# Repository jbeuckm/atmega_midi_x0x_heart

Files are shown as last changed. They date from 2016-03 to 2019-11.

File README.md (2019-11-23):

# MIDI interface for x0x heart

Atmega328 MIDI interface for the x0x heart http://www.openmusiclabs.com/projects/x0x-heart/

One-sided for easy home DIY.

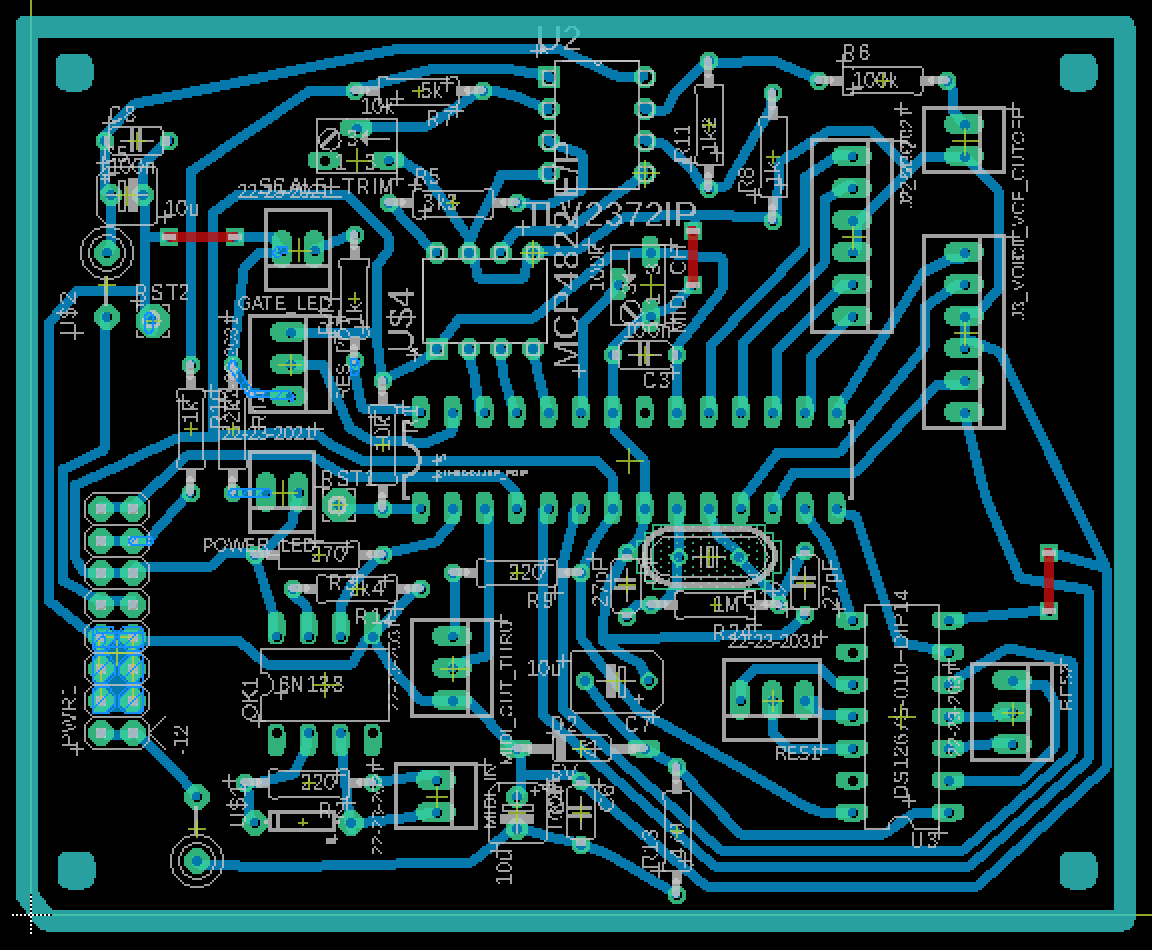
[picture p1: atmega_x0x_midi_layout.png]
atmega_x0x_midi_layout


### NOTE ON/OFF

The gate pins of the eurorack connector are raised to 5V during the note. The "CV" pins of the eurorack connector are set to 1V/oct pitch control voltage. A pitch scale trimpot can be used to tune the x0x.

### Continuous Controllers

| MIDI CC | Function |
| --- | --- |
| 1 | Envelope |
| 2 | Resonance |
| 11 | Accent |
| 65 | Slide above 64 / No slide below 64 |
| 70 | Saw level |
| 71 | Square level |
| 72 | Decay |
| 74 | VCF Cutoff |

### System Exclusive

MIDI Sysex messages for this device begin with a four-byte prefix of the Sysex status byte, manufacturer ID, model ID and device ID.

`F0` sysex start

`77 33` manufacturer ID, model ID

`xx` device ID as set by trim pot

--

#### Set MIDI Channel

At startup, the MIDI channel of the device is the same as the device ID set with the trim pot.

A seven-byte sysex message can be used to change the channel of the interface.

`F0 77 33 xx` sysex prefix

`00` select MIDI channel parameter

`xx` new MIDI channel (0 for omni)

`F7` end of message

--

#### Patch Dump Request

A six-byte sysex message can be used to request a dump of the current voice parameters.

`F0 77 33 xx` sysex prefix

`01` patch dump request

`F7` end of message

The interface will then send a patch dump sysex message that encodes the current voice parameter values.

`F0 77 33 xx` sysex prefix

`02` patch dump

`ee rr aa pp ss qq dd ff`

envelope, resonance, accent, slide, saw, square, decay, cutoff (eight bytes)

`F7` end of message

This dumped patch data can be used to set all voice parameters by sending it back to the interface.

--

#### Save Patch

`F0 77 33 xx` sysex prefix

`11` save patch

`pp` patch number (0-127)

`F7` end of message

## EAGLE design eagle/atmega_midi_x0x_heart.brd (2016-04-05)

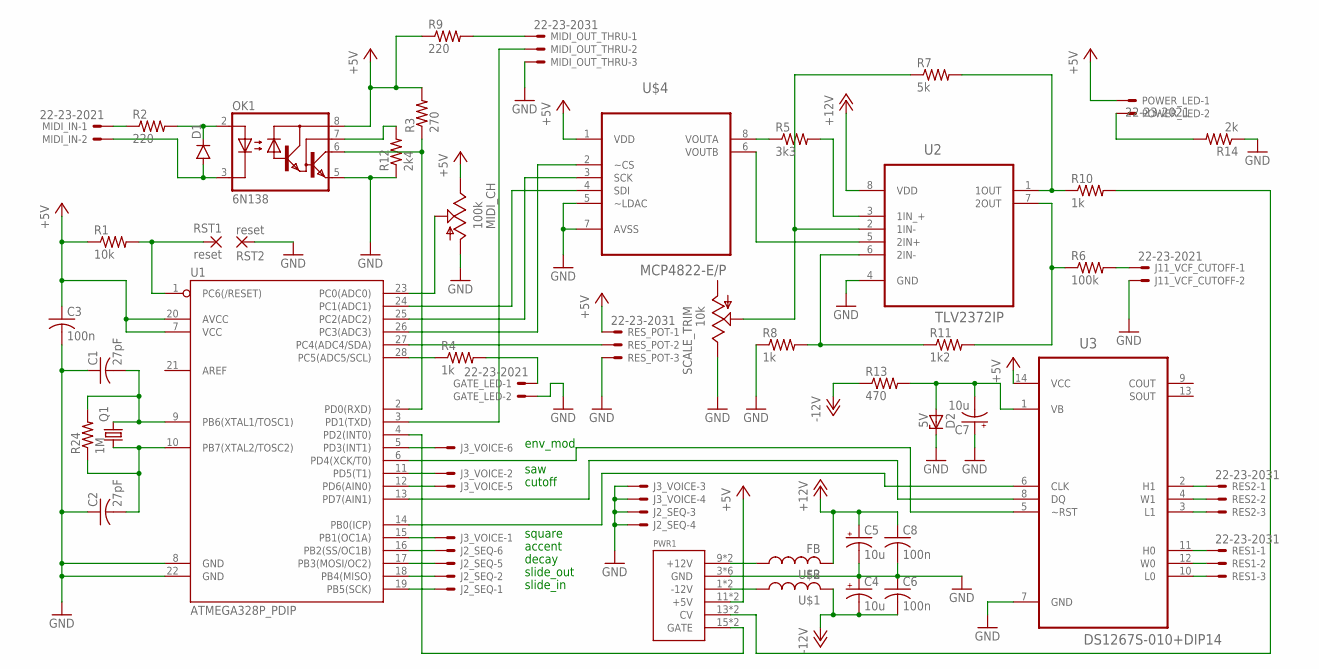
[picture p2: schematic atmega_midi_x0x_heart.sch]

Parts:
C1, C2: 27pF; C050-024X044
C3, C6, C8: 100n; C050-024X044
C4, C5: 10u; B45181A
C7: 10u; B45181B
D1: DIODE1N4148; DIODE-1N4148
D2: 5V; DO35Z10
GATE_LED: 22-23-2021
J2_SEQ, J3_VOICE: 22-23-2061
J11_VCF_CUTOFF: 22-23-2021
MIDI_CH: 100k; B64W
MIDI_IN: 22-23-2021
MIDI_OUT_THRU: 22-23-2031
OK1: 6N138; DIL08
POWER_LED: 22-23-2021
PWR1: POWER; POWER_16
Q1: CRYSTALHC49S; HC49/S
R1: 10k; 0207/10
R2, R9: 220; 0207/10
R3: 270; 0207/10
R4, R8, R10: 1k; 0207/10
R5: 3k3; 0207/10
R6: 100k; 0207/10
R7: 5k; 0207/10
R11: 1k2; 0207/10
R12: 2k4; 0207/10
R13: 470; 0207/10
R14: 2k; 0207/10
R24: 1M; 0207/10
RES1, RES2: 22-23-2031
RES_POT: 22-23-2031
RST1, RST2: reset; 2,54/0,9
SCALE_TRIM: 10k; B64W
U1: ATMEGA328P_PDIP; DIL28-3
U2: TLV2372IP; DIP254P762X508-8
U3: DS1267S-010+DIP14; DIP14
U$1, U$2: FB
U$4: MCP4822-E/P; DIP254P762X432-8

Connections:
+5V: C3.1, MIDI_CH.E, OK1.8 (VCC), POWER_LED.1, PWR1.11 (+5V), PWR1.12 (+5V), R1.1, R3.2, R9.1, RES_POT.1, U1.7 (VCC), U1.20 (AVCC), U3.14 (VCC), U$4.1 (VDD)
+12V: C5.+, C8.1, U2.8 (VDD), U$2.P$2 (2)
-12V: C4.-, C6.2, R13.1, U$1.P$2 (2)
GND: C1.1, C2.1, C3.2, C4.+, C5.-, C6.1, C7.+, C8.2, D2.C, GATE_LED.2, J2_SEQ.3, J2_SEQ.4, J3_VOICE.3, J3_VOICE.4, J11_VCF_CUTOFF.2, MIDI_CH.A, MIDI_OUT_THRU.3, OK1.5 (GND), PWR1.3 (GND), PWR1.4 (GND), PWR1.5 (GND), PWR1.6 (GND), PWR1.7 (GND), PWR1.8 (GND), R8.1, R12.1, R14.1, RES_POT.3, RST2.1, SCALE_TRIM.E, U1.8 (GND), U1.22 (GND), U2.4 (GND), U3.7 (GND), U$4.5 (~LDAC), U$4.7 (AVSS)
unnamed: J3_VOICE.6, U1.5 (PD3(INT1))
unnamed: R5.1, U$4.8 (VOUTA)
unnamed: D1.A, MIDI_IN.2, OK1.3 (C)
unnamed: C1.2, Q1.2, R24.2, U1.9 (PB6(XTAL1/TOSC1))
unnamed: C2.2, Q1.1, R24.1, U1.10 (PB7(XTAL2/TOSC2))
unnamed: R5.2, U2.3 (1IN_+)
unnamed: D1.C, OK1.2 (A), R2.2
unnamed: MIDI_IN.1, R2.1
unnamed: J3_VOICE.1, U1.15 (PB1(OC1A))
unnamed: J3_VOICE.2, U1.11 (PD5(T1))
unnamed: PWR1.9 (+12V), PWR1.10 (+12V), U$2.P$1 (1)
unnamed: R7.1, SCALE_TRIM.S, U2.2 (1IN-)
unnamed: R8.2, R11.1, U2.6 (2IN-)
unnamed: U2.5 (2IN+), U$4.6 (VOUTB)
unnamed: PWR1.13 (CV), PWR1.14 (CV), R10.2
unnamed: J3_VOICE.5, U1.12 (PD6(AIN0))
unnamed: R6.1, R11.2, U2.7 (2OUT)
unnamed: J2_SEQ.1, U1.19 (PB5(SCK))
unnamed: MIDI_CH.S, U1.23 (PC0(ADC0))
unnamed: J2_SEQ.2, U1.18 (PB4(MISO))
unnamed: J2_SEQ.5, U1.17 (PB3(MOSI/OC2))
unnamed: U1.6 (PD4(XCK/T0)), U3.5 (~RST)
unnamed: J2_SEQ.6, U1.16 (PB2(SS/OC1B))
unnamed: GATE_LED.1, R4.2
unnamed: U1.25 (PC2(ADC2)), U$4.3 (SCK)
unnamed: U1.24 (PC1(ADC1)), U$4.4 (SDI)
unnamed: R7.2, R10.1, U2.1 (1OUT)
unnamed: R4.1, U1.28 (PC5(ADC5/SCL))
unnamed: J11_VCF_CUTOFF.1, R6.2
unnamed: OK1.6 (VO), R3.1, U1.2 (PD0(RXD))
unnamed: RES2.2, U3.4 (W1)
unnamed: RES2.1, U3.2 (H1)
unnamed: RES2.3, U3.3 (L1)
unnamed: RES1.2, U3.12 (W0)
unnamed: RES1.1, U3.11 (H0)
unnamed: RES1.3, U3.10 (L0)
unnamed: U1.14 (PB0(ICP)), U3.6 (CLK)
unnamed: RES_POT.2, U1.27 (PC4(ADC4/SDA))
unnamed: MIDI_OUT_THRU.1, R9.2
unnamed: PWR1.15 (GATE), PWR1.16 (GATE), U1.4 (PD2(INT0))
unnamed: U1.13 (PD7(AIN1)), U3.8 (DQ)
unnamed: MIDI_OUT_THRU.2, U1.3 (PD1(TXD))
unnamed: R1.2, RST1.1, U1.1 (PC6(/RESET))
unnamed: OK1.7 (VB), R12.2
unnamed: U1.26 (PC3(ADC3)), U$4.2 (~CS)
unnamed: POWER_LED.2, R14.2
unnamed: PWR1.1 (-12V), PWR1.2 (-12V), U$1.P$1 (1)
unnamed: C7.-, D2.A, R13.2, U3.1 (VB)

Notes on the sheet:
square
saw
cutoff
env_mod
slide_in
slide_out
decay
accent

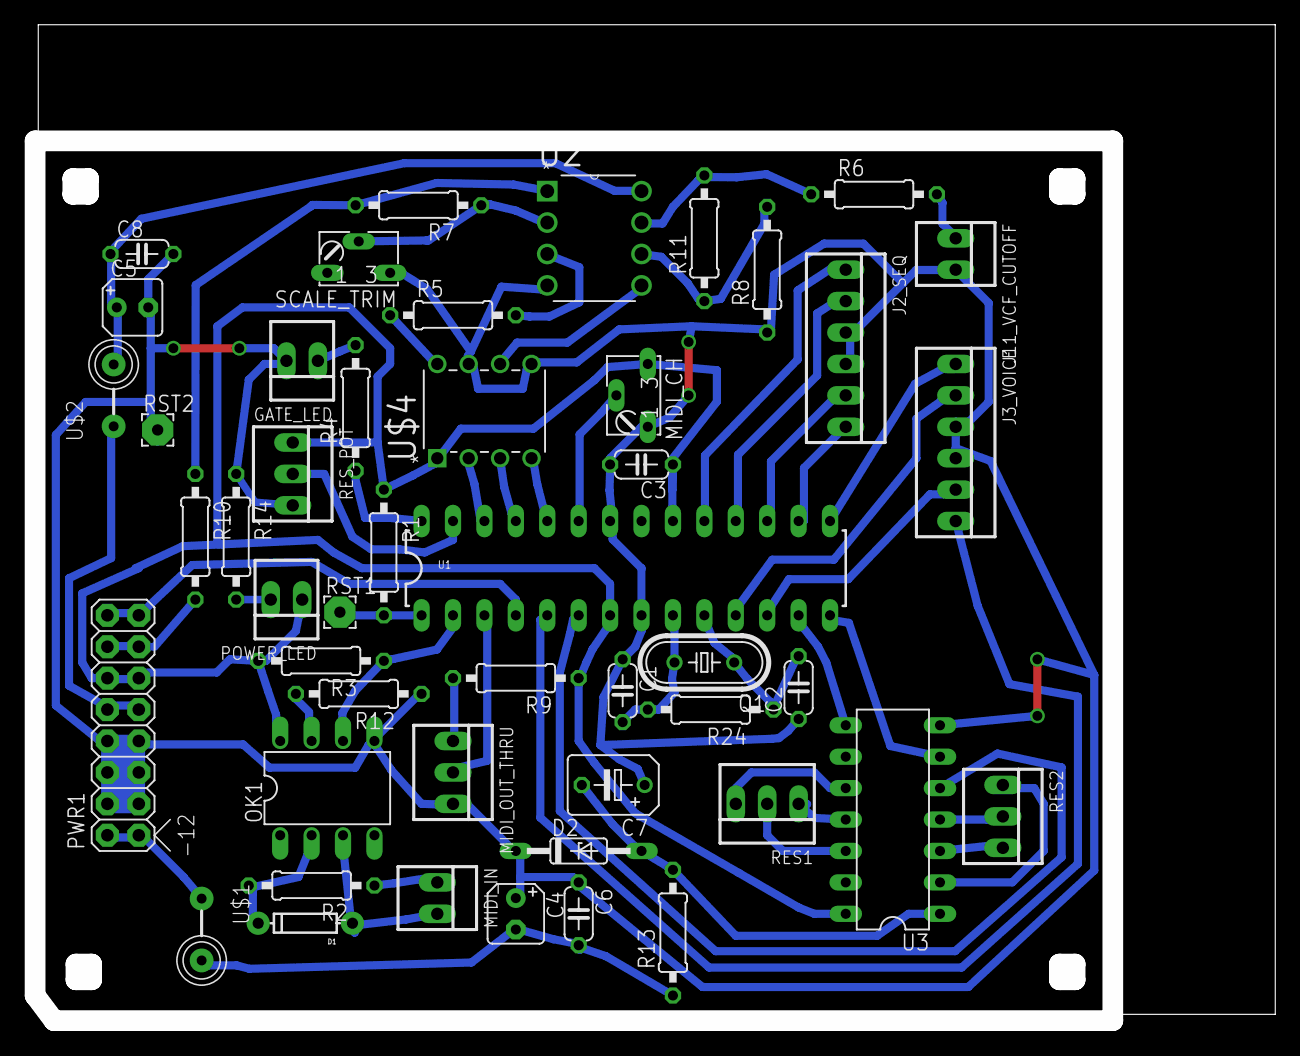
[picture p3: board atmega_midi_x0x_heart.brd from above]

Board: 2 copper layers, 100.3 x 80.5 mm, 48 parts (0 on the bottom side), 52 nets.

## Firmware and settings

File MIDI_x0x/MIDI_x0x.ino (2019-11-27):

#include <MIDI.h>
#include <AH_MCP4922.h>
#include <DS1267.h>
#include <EEPROM.h>

#define GATE_PIN 2
#define GATE_LED A5

#define ENV_MOD_CTRL 1
#define ENV_MOD_PIN 3

#define CUTOFF_CTRL 74
#define CUTOFF_PIN 6

#define SAW_CTRL 70
#define SAW_PIN 5
#define SQR_CTRL 71
#define SQR_PIN 9

#define SLIDE_CTRL 65
#define SLIDE_TIME_CTRL 5
#define SLIDE_IN_PIN 13
#define SLIDE_OUT_PIN 12

#define DECAY_CTRL 72
#define DECAY_PIN 11

#define ACCENT_CTRL 11
#define ACCENT_PIN 10

#define RES_CTRL 2
#define RES_POT_PIN A4

#define ALL_NOTES_OFF 123
#define CTRL_RESET 121

AH_MCP4922 PitchDac(A1, A2, A3, LOW, LOW);

AH_MCP4922 CutoffDac(A1, A2, A3, HIGH, LOW);

// dual digipot to control x0x resonance programatically
DS1267 ResonancePot(8, 7, 4);


int liveNoteCount = 0;
int pitchbendOffset = 0;
int baseNoteFrequency;

byte deviceID;

MIDI_CREATE_DEFAULT_INSTANCE();

// these hold the current settings
byte envelopeLevel, cutoff, resonance, accent, sawLevel, squareLevel, slide, decay;


void handleNoteOn(byte channel, byte pitch, byte velocity)
{
  liveNoteCount++;

  // set the CC-specified ACCENT level for strong notes
  if (velocity >= 100) {
    analogWrite(ACCENT_PIN, int(accent) << 1);
  } else {
    analogWrite(ACCENT_PIN, 0);
  }

  baseNoteFrequency = (pitch - 12) * 42;
  PitchDac.setValue(baseNoteFrequency + pitchbendOffset);

  digitalWrite(GATE_PIN, HIGH);
  digitalWrite(GATE_LED, HIGH);
}


void handleNoteOff(byte channel, byte pitch, byte velocity)
{
  liveNoteCount--;

  if (liveNoteCount <= 0) {
    digitalWrite(GATE_PIN, LOW);
    digitalWrite(GATE_LED, LOW);
  }
}


// variables for managing resonance pot input value
int resControllerValue, lastResControllerValue, resPotValue;
float resPotRecentAvg = 0;


void handleControlChange(byte channel, byte number, byte value) {
  int scaledValue = int(value) << 1;

  switch (number) {

    case CUTOFF_CTRL:
      CutoffDac.setValue(value << 5);
      cutoff = value;
      break;

    case ENV_MOD_CTRL:
      analogWrite(ENV_MOD_PIN, scaledValue);
      envelopeLevel = value;
      break;

    case SAW_CTRL:
      analogWrite(SAW_PIN, scaledValue);
      sawLevel = value;
      break;

    case SQR_CTRL:
      analogWrite(SQR_PIN, scaledValue);
      squareLevel = value;
      break;

    case DECAY_CTRL:
      analogWrite(DECAY_PIN, 255 - scaledValue);
      decay = value;
      break;

    case ACCENT_CTRL:
      accent = value;
      break;

    case SLIDE_CTRL:
      if (value >= 64) {
        digitalWrite(SLIDE_IN_PIN, HIGH);
        digitalWrite(SLIDE_OUT_PIN, LOW);
      } else {
        digitalWrite(SLIDE_IN_PIN, LOW);
        digitalWrite(SLIDE_OUT_PIN, HIGH);
      }
      slide = value;
      break;

    case RES_CTRL:
      ResonancePot.setValue(255 - scaledValue, 255 - scaledValue, 0);
      resonance = value;
      break;

    case ALL_NOTES_OFF:
      liveNoteCount = 0;
      handlePitchBend(deviceID, 0);
      digitalWrite(GATE_PIN, LOW);
      digitalWrite(GATE_LED, LOW);
      break;
  }

}


void handlePitchBend(byte channel, int bend) {
  pitchbendOffset = bend >> 4;

  PitchDac.setValue(baseNoteFrequency + pitchbendOffset);
}


void handleSystemExclusive(byte message[], unsigned size) {

  if (message[1] != 0x77) return;      // manufacturer ID
  if (message[2] != 0x33) return;      // model ID
  if (message[3] != deviceID) return;  // device ID as set with trim pot

  switch (message[4]) {

    case 0x00:
      setMidiChannel(message[5]);
      break;

    case 0x01:
      sendPatchDump();
      break;

    case 0x02:
      receivePatchDump(message);
      break;

    case 0x11:
      saveProgram(message[5]);

    default:
      break;
  }

}


void saveProgram(char progNumber) {

  int offset = 8 * progNumber;

  EEPROM.update(offset++, envelopeLevel);
  EEPROM.update(offset++, resonance);
  EEPROM.update(offset++, accent);
  EEPROM.update(offset++, slide);

  EEPROM.update(offset++, sawLevel);
  EEPROM.update(offset++, squareLevel);
  EEPROM.update(offset++, decay);
  EEPROM.update(offset, cutoff);
}

void handleProgramChange(byte channel, byte number) {

  int offset = 8 * number;

  envelopeLevel = EEPROM.read(offset++);
  resonance = EEPROM.read(offset++);
  accent = EEPROM.read(offset++);
  slide = EEPROM.read(offset++);

  sawLevel = EEPROM.read(offset++);
  squareLevel = EEPROM.read(offset++);
  decay = EEPROM.read(offset++);
  cutoff = EEPROM.read(offset);
}


void sendPatchDump() {

  byte sysexArray[] = { 0xf0, 0x77, 0x33, deviceID, 0x02, 0, 0, 0, 0, 0, 0, 0, 0, 0xf7 };

  int paramByte = 5;

  sysexArray[paramByte++] = envelopeLevel;
  sysexArray[paramByte++] = resonance;
  sysexArray[paramByte++] = accent;
  sysexArray[paramByte++] = slide;

  sysexArray[paramByte++] = sawLevel;
  sysexArray[paramByte++] = squareLevel;
  sysexArray[paramByte++] = decay;
  sysexArray[paramByte] = cutoff;

  MIDI.sendSysEx(14, sysexArray, true);
}


void receivePatchDump(byte message[]) {

  int paramByte = 5;

  handleControlChange(deviceID, ENV_MOD_CTRL, message[paramByte++]);
  handleControlChange(deviceID, RES_CTRL, message[paramByte++]);
  handleControlChange(deviceID, ACCENT_CTRL, message[paramByte++]);
  handleControlChange(deviceID, SLIDE_CTRL, message[paramByte++]);

  handleControlChange(deviceID, SAW_CTRL, message[paramByte++]);
  handleControlChange(deviceID, SQR_CTRL, message[paramByte++]);
  handleControlChange(deviceID, DECAY_CTRL, message[paramByte++]);
  handleControlChange(deviceID, CUTOFF_CTRL, message[paramByte++]);
}


void setMidiChannel(byte newChannel) {

  MIDI.begin(newChannel % 17);
  playScale(newChannel % 17);

}

// -----------------------------------------------------------------------------

void setup() {
  int channelSpan = 1024 / 16;
  int channelInput = analogRead(0);
  deviceID = channelInput / channelSpan;

  TCCR0B = (TCCR0B & 0b11111000) | 0x01;
  TCCR1B = (TCCR1B & 0b11111000) | 0x01;
  TCCR2B = (TCCR2B & 0b11111000) | 0x01;

  pinMode(GATE_PIN, OUTPUT);
  digitalWrite(GATE_PIN, LOW);
  pinMode(GATE_LED, OUTPUT);
  digitalWrite(GATE_LED, LOW);


  digitalWrite(SLIDE_IN_PIN, OUTPUT);
  digitalWrite(SLIDE_IN_PIN, LOW);
  digitalWrite(SLIDE_OUT_PIN, OUTPUT);
  digitalWrite(SLIDE_OUT_PIN, HIGH);
  slide = 0;

  pinMode(ENV_MOD_PIN, OUTPUT);
  digitalWrite(ENV_MOD_PIN, HIGH);
  envelopeLevel = 127;

  pinMode(SAW_PIN, OUTPUT);
  digitalWrite(SAW_PIN, HIGH);
  sawLevel = 127;

  pinMode(SQR_PIN, OUTPUT);
  digitalWrite(SQR_PIN, LOW);
  squareLevel = 0;

  pinMode(CUTOFF_PIN, OUTPUT);
  digitalWrite(CUTOFF_PIN, LOW);
  cutoff = 0;

  pinMode(DECAY_PIN, OUTPUT);
  digitalWrite(DECAY_PIN, LOW);
  decay = 0;

  pinMode(ACCENT_PIN, OUTPUT);
  digitalWrite(ACCENT_PIN, LOW);
  accent = 0;

  delay(1000);

  // init resonance running avg to avoid sending event at startup
  resPotRecentAvg = analogRead(RES_POT_PIN);
  lastResControllerValue = 127 - ((int)resPotRecentAvg >> 3);

  playScale(deviceID);

  // calibrate 8V
  baseNoteFrequency = (108 - 12) * 42;
  PitchDac.setValue(baseNoteFrequency);

  // calibrate full cutoff
  CutoffDac.setValue(32 * 127);
  cutoff = 127;

  MIDI.setHandleNoteOn(handleNoteOn);
  MIDI.setHandleNoteOff(handleNoteOff);
  MIDI.setHandlePitchBend(handlePitchBend);
  MIDI.setHandleControlChange(handleControlChange);

  MIDI.setHandleSystemExclusive(handleSystemExclusive);
  MIDI.setHandleProgramChange(handleProgramChange);

  MIDI.begin(deviceID);
  MIDI.turnThruOff();
}


void playScale(int channel) {

  int note = 60;

  for (int i = 0; i < channel; i++) {

    handleNoteOn(channel, note, 100);
    delay(5000);
    handleNoteOff(channel, note, 100);
    delay(5000);
    note++;
  }

}

void loop() {
  resPotValue = analogRead(RES_POT_PIN);
  resPotRecentAvg = .2 * (float)resPotValue + .8 * resPotRecentAvg;

  resControllerValue = 127 - ((int)resPotRecentAvg >> 3);

  if (abs(lastResControllerValue - resControllerValue) > 1) {
    lastResControllerValue = resControllerValue;
    handleControlChange(deviceID, RES_CTRL, resControllerValue);
    resonance = resControllerValue;
    MIDI.sendControlChange(RES_CTRL, resControllerValue, deviceID);
  }

  MIDI.read();
}

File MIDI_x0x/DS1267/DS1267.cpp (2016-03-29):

#include "Arduino.h"
#include "DS1267.h"


DS1267::DS1267(int clkPin, int dqPin, int resetPin) {

    _clkPin = clkPin;
    pinMode(_clkPin, OUTPUT);
    _dqPin = dqPin;
    pinMode(_dqPin, OUTPUT);
    _resetPin = resetPin;
    pinMode(_resetPin, OUTPUT);

	digitalWrite(_resetPin, LOW);
	digitalWrite(_clkPin, LOW);
	digitalWrite(_dqPin, LOW);
}


void DS1267::setValue(byte pot1value, byte pot2value, byte stackBit) {

    digitalWrite(_resetPin, HIGH);
    delayMicroseconds(1);

    if (stackBit){
      digitalWrite(_dqPin, HIGH);
    }
    else{
      digitalWrite(_dqPin, LOW);
    }

    delayMicroseconds(1);
    digitalWrite(_clkPin, HIGH);
    delayMicroseconds(1);
    digitalWrite(_clkPin, LOW);
    delayMicroseconds(1);

    byte mask;
    
  for (mask = B10000000; mask>0; mask >>= 1) {

    if (pot1value & mask){
      digitalWrite(_dqPin, HIGH);
    }
    else{
      digitalWrite(_dqPin, LOW);
    }

    delayMicroseconds(1);
	digitalWrite(_clkPin, HIGH);
    delayMicroseconds(1);
	digitalWrite(_clkPin, LOW);
    delayMicroseconds(1);

  }


  for (mask = B10000000; mask>0; mask >>= 1) {

    if (pot2value & mask){
      digitalWrite(_dqPin, HIGH);
    }
    else{
      digitalWrite(_dqPin, LOW);
    }

    delayMicroseconds(1);
	digitalWrite(_clkPin, HIGH);
    delayMicroseconds(1);
	digitalWrite(_clkPin, LOW);
    delayMicroseconds(1);

  }

	digitalWrite(_resetPin, LOW);
    delayMicroseconds(1);    
}

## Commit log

2016-02-11 working up schemo
    [atmega_midi_x0x_heart.brd, atmega_midi_x0x_heart.sch, basic_midi_cv_panel.dxf]
2016-02-12 pwm pins connected in schemo
    [atmega_midi_x0x_heart.brd, atmega_midi_x0x_heart.sch]
2016-02-12 niced up schemo
    [atmega_midi_x0x_heart.brd, atmega_midi_x0x_heart.sch]
2016-02-13 started up the layout
    [atmega_midi_x0x_heart.brd]
2016-02-13 pretty good positioning
    [atmega_midi_x0x_heart.brd, atmega_midi_x0x_heart.sch]
2016-02-13 rebuilt brd with redone gnd
    [atmega_midi_x0x_heart.brd, atmega_midi_x0x_heart.sch]
2016-02-13 nearly routed
    [atmega_midi_x0x_heart.brd, atmega_midi_x0x_heart.sch]
2016-02-13 setting up pin constants and added gate led
    [atmega_midi_x0x_heart.brd, atmega_midi_x0x_heart.sch]
2016-02-14 pin and midi controller number constants
2016-02-15 fixed touching trace
    [atmega_midi_x0x_heart.brd]
2016-02-15 moved J2 away from midi channel trim
    [atmega_midi_x0x_heart.brd]
2016-02-15 configured timers for faster-than-sound PWM
2016-02-16 brd tweaks
    [atmega_midi_x0x_heart.brd]
2016-02-25 added vcf output resistor
    [atmega_midi_x0x_heart.brd, atmega_midi_x0x_heart.sch]
2016-03-06 disabling interrupts during midi and more permissive gate on condition
2016-03-09 changed to TI precision opamp
    [atmega_midi_x0x_heart.brd, atmega_midi_x0x_heart.sch]
2016-03-09 tweaked cutout for better holes
    [atmega_midi_x0x_heart.brd, atmega_midi_x0x_heart.sch]
2016-03-09 digital pot and midi out
    [atmega_midi_x0x_heart.brd, atmega_midi_x0x_heart.sch]
2016-03-09 initial layout for res control version
    [atmega_midi_x0x_heart.brd, atmega_midi_x0x_heart.sch]
2016-03-09 brd drc
    [atmega_midi_x0x_heart.brd]
2016-03-10 layout tweaks
    [atmega_midi_x0x_heart.brd, atmega_midi_x0x_heart.sch]
2016-03-10 97 pct autorouted
    [atmega_midi_x0x_heart.brd, atmega_midi_x0x_heart.sch]
2016-03-10 switched gate and pot ctrl pins for positioning
    [atmega_midi_x0x_heart.brd, atmega_midi_x0x_heart.sch]
2016-03-13 ready to cut
    [atmega_midi_x0x_heart.brd]
2016-03-16 ds1267 is there
    [atmega_midi_x0x_heart.brd, atmega_midi_x0x_heart.sch]
2016-03-16 power led
    [atmega_midi_x0x_heart.brd, atmega_midi_x0x_heart.sch]
2016-03-16 leds converted to connectors
    [atmega_midi_x0x_heart.brd, atmega_midi_x0x_heart.sch]
2016-03-16 schemo tweaks
    [atmega_midi_x0x_heart.sch]
2016-03-16 high 80s autoroute
    [atmega_midi_x0x_heart.brd]
2016-03-17 using molex friction parts
    [atmega_midi_x0x_heart.brd, atmega_midi_x0x_heart.sch]
2016-03-17 90pct auto
    [atmega_midi_x0x_heart.brd, atmega_midi_x0x_heart.sch]
2016-03-17 possibly routed
    [atmega_midi_x0x_heart.brd, atmega_midi_x0x_heart.sch]
2016-03-17 board tweaks
    [atmega_midi_x0x_heart.brd]
2016-03-19 tweaks and cutout
    [atmega_midi_x0x_heart.brd]
2016-03-27 corrected midi led pin and built prototype produces gate led correctly
    [DAC_MCP4922_H.pde, MIDI_x0x.ino]
2016-04-05 reversed resonance and fixed a couple of pins
    [atmega_midi_x0x_heart.brd, atmega_midi_x0x_heart.sch]
2016-07-18 cleanup and dac code included
    [basic_midi_cv_panel.dxf]
2016-10-20 setting VCF CV with controller instead of velocity and no PWM VCF
2017-04-16 midi device paqnel for cubase
2019-11-27 set high PWM freq before setPinMode() and accent when velocity > 100

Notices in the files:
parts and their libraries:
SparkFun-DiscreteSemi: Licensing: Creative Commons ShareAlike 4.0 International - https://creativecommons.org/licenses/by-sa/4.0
